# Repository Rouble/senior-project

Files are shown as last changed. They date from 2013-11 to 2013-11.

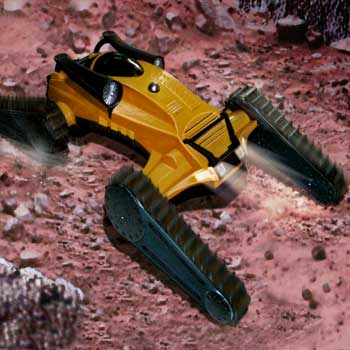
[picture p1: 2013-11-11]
TanTarantula.jpg

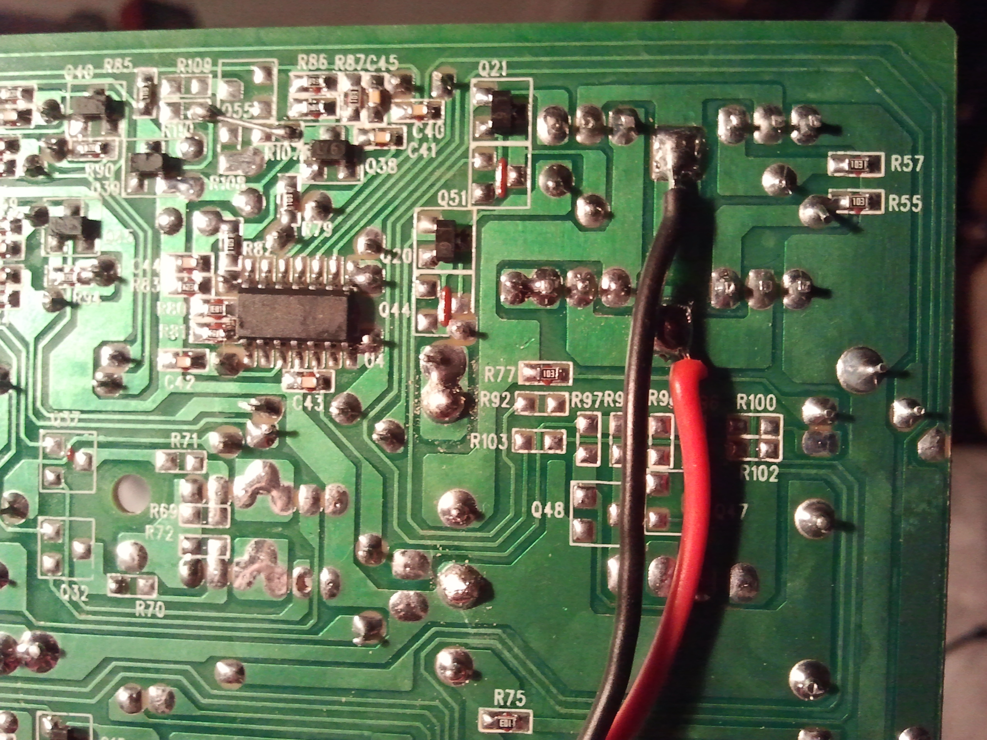
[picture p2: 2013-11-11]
H-bridge board/2013-01-09 15.14.43.jpg

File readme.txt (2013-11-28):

Senior project to preplace a missing remote for an RC car from scratch.
Used a Playstation one controller to house controls (doubles as wireless USB game pad)

Code was written in C++ in Atmel studio 6.0 for the ATMega32u4 microcontoller to interface with 
the Cypress CYRF8935 2.4GHz transciever 

"H-bridge board" contains files related to the motor drive circuit board contained in the RC car
needed to wire in replacement reciver/control module

PCB design documents created with Altium Designer 13 Design folder contains PDFs of all designs

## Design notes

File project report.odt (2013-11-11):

Remote Controlled Vehicle

Chris Elkins

Senior Design

ECET 4370

Dr. Steve Menhart

Replacement control circuitry was designed for a discarded toy car and old game controller to replace the original remote for the car. The system was designed to use an antenna printed on the circuit boards and communicate in the 2.4GHz band.

# Introduction

The Tarantula, manufactured by MGA Entertainment through 2004. It was designed to be an all terrain remote controlled car using tank-like treads for locomotion and used “flippers” to lift the body of the vehicle up and over obstacles. It was available with operating frequencies of 27 and 49MHz and like many remote controlled vehicles at the time, came with a large awkward controller. The available one was missing the remote control the purpose of this endeavor was to create a device to restore it to working order.

# Design Considerations

The tarantula was disassembled and a schematic of the motor driver board was created to identify the function of each input pin. Several connectors were removed from the original control board and reused in the final design.

MGA Tarantula

An original Playstation controller was chosen to house the transmitter circuitry because the layout of the inputs allowed for easy to hold, and easy to use controls of the tank style drive system of the vehicle. The controller was disassembled and measurements were made of the original circuit board to create a replacement board of identical dimensions. The Playstation controller circuit board contained a flexible flat cable (FFC) connector used to connect the buttons to the circuit board, this FFC connector was reused in the final design to reduce cost. The controller did not initially have space for a battery, however after the removal of the rumble motors and their mounting brackets there was enough room to include a rechargeable lithium-ion or lithium-polymer battery inside the grips.

The Atmel ATMega32U4 micro controller (MCU) was chosen for the design for the following reasons:

- Large online support communities
- Minimal external programming hardware (uses integrated USB)
- Variety of communication interfaces
- More than enough analog inputs to read joystick values on the remote
- Enough general purpose I/O pins to read all the buttons on the remote
- Sufficient pulse-width modulation outputs to drive the vehicle's H-bridges

The transmitting frequency of 2.4GHz was chosen to allow a more compact design by allowing the antenna to be printed directly on the circuit boards. The Cypress CYRF8935 transceiver was picked to handle the wireless communication, it was chosen for its price and compatibility with the ATMega32U4. The Cypress transceiver can handle transmission errors in hardware using forward error correction and cyclic redundancy checking and can automatically retransmit erroneous packets.

Insufficient information was found to design a printed antenna, so a design from Texas Instruments (application note AN043) was used. A controlled 50Ω impedance trace from the transceiver to the antenna was created using the equation Z_o = 87 over sqrt {%varepsilon_r + 1.41} ln(5.98H over {0.8W + T} ) "where "Z_o "is the impedance, " %varepsilon_r " is the relative permittivity of the circuit board dielectric material, H is" newline "the thickness of the dielectric material, W is the width of the trace, and T is the thickness of the trace. " newline
"Average values for " %varepsilon_r ", H, and T were used in the calculation, 4.5, 62 mil, and 1.37 mil respectively "newline"for FR4, this gave a resulting trace width of 108 mil.

# Results

After the circuit boards were assembled several several errors were discovered with the boards. The data lines for the USB connections were reversed, the transceiver's crystal oscillator ground pads were not grounded and the transceiver required a pulse on its reset pin during initialization however the MCU was not connected to the transceiver's reset line. These mistakes were easily corrected using small gauge wire, and corrected on the board layouts and schematics included with this report.

The antennas were tested using a network analyzer and determined to have a resonant frequency of approximately 1.9GHz and poorly impedance matched. The board thickness was measured and found to be only 55 mil. The relative permittivity of the FR4 board was found to be around 5.9 by making a spare board into a crude parallel plate capacitor to approximately measure the relative permittivity by using the equation C ={ %varepsilon_r %varepsilon_0 A }over d " where "%varepsilon_0" is the permittivity of space, A is the area of the plates and d is the distance between the plates, the capacitance was measured to be 8.4pF. The actual values for the board were used in the trace impedance equation which showed that the actual impedance of the trace was close to 42Ω explaining the impedance mismatch on the antenna.

It was discovered that the transceivers would intermittently initialize incorrectly and return garbled data or not transfer wireless data at all, a likely cause was determined to be the MCU starting up at a low voltage and attempting to initialize the transceiver before it was ready. A relatively long delay of approximately 200ms was added before the initialization instructions were sent by the MCU, the errant behavior did not occur again, confirming the cause.

When the vehicle was set to full speed it would move for a fraction of a second then stop and make a periodic clicking sound, connecting an oscilloscope to the power rail revealed that when spinning up, one of the drive motors caused the output voltage to drop drastically when first powered up, this caused the MCU to reset. A large valued electrolytic capacitor was placed across the input, this greatly reduced the problem, however a larger capacitor is required to eliminate it.

# Conclusions

The remote design could be improved by using a much smaller battery that fits completely inside the controller. It would also benefit from the use of a “soft latch” circuit for power as opposed to the current physical switch protruding from the back. The design should have used a passive component circuit to adjust the impedance of the feed trace to the antenna.

# APPENDIX

/* remote.cpp

*

* Created: 3/10/2013 ☢ 16:43:55 ☢

* Author: Chris

*/

#define F_CPU 8000000UL //define cpu frequency as 8MHz for the _delay_() macro

#include <avr/io.h>

#include <avr/interrupt.h>

#include <util/delay.h>

#include "a2d.h"

#include "xcvr.h"

#include "usb_mouse_debug.h"

#include "print.h"

#define _left (PIND & (1<<PIND6)) //pin status checks for readability

#define _right (PIND & (1<<PIND5))

#define _up (PIND & (1<<PIND3))

#define _down (PIND & (1<<PIND4))

#define _tri (PINC & (1<<PINC7))

#define _ex (PINF & (1<<PINF7))

#define _squ (PINF & (1<<PINF6))

#define _cir (PINE & (1<<PINE2))

#define _L1 (PIND & (1<<PIND2))

#define _L2 (PIND & (1<<PIND1))

#define _L3 (PINB & (1<<PINB7))

#define _R1 (PINC & (1<<PINC6))

#define _R2 (PINB & (1<<PINB6))

#define _R3 (PIND & (1<<PIND0))

#define _start (PINB & (1<<PINB5))

#define _select (PINB & (1<<PINB4))

#define packlen 0 //offsets for input array readability

#define buttons1 1

#define buttons2 2

#define dpad 2

#define rightVanalog 3

#define rightHanalog 4

#define leftVanalog 5

#define leftHanalog 6

void pinsetup(); //configures I/O pins

void update_inputs(char input[]); //populates the remote_input array with all input data

void unused_modules(); //turn off unused modules

void start_usb();

static int potatoes[] = {0x706f, 0x7461, 0x746f, 0x6573}; //the sync key is potatoes. because potatoes.

int main(void)

{

char remote_input[7] = {0};

CLKPR = 0x80; //prepare clock prescaler for change

CLKPR = 1; //divide clock by 2

XCVR XC = XCVR(10, potatoes, TX_EN);

pinsetup(); //setup pins

ADCon(); //start the ADC module

unused_modules(); //turn extra stuff off

start_usb(); //check for usb connection / enable usb

while(1)

{

update_inputs(remote_input); //update values for buttons/analogs

XC.tx(remote_input, 7);

_delay_ms(50);

}

}

void pinsetup()

{

//disable digital input functionality of adc pins 5,4,1,0 (reduces power consumption)

DIDR0 = 0x33;

//enable internal pullups for

PORTB |= (1<<PORTB4)|(1<<PORTB5)|(1<<PORTB6)|(1<<PORTB7);

PORTC |= (1<<PORTC6)|(1<<PORTC7);

PORTD = 0x7F;

PORTE |= (1<<PORTE2);

PORTF |= (1<<PORTF6)|(1<<PORTF7);

DDRE |= (1<<DDE6); //charge mode pin = output

}

void update_inputs(char input[])

{

input[packlen] = 6; //packet length

input[buttons1] = 0; //clear button data

input[dpad] = 0;

//if button pressed set bit in array

if (!_tri) input[buttons1] |= 0x01;

if (!_cir) input[buttons1] |= 0x02;

if (!_ex) input[buttons1] |= 0x04;

if (!_squ) input[buttons1] |= 0x08;

if (!_L2) input[buttons1] |= 0x10;

if (!_R2) input[buttons1] |= 0x20;

if (!_L1) input[buttons1] |= 0x40;

if (!_R1) input[buttons1] |= 0x80;

if (!_select) input[buttons2] |= 0x10;

if (!_start) input[buttons2] |= 0x20;

if (!_L3) input[buttons2] |= 0x40;

if (!_R3) input[buttons2] |= 0x80;

if (!_up) input[dpad] |= 0x01;

if (!_right) input[dpad] |= 0x02;

if (!_down) input[dpad] |= 0x04;

if (!_left) input[dpad] |= 0x08;

switch (input[dpad] & 0x0F) //USB HID directional pad position data is weird

{ //cardinal direction

case 1: input[dpad] = (input[dpad] & 0xF0) | 0; break; //N

case 2: input[dpad] = (input[dpad] & 0xF0) | 2; break; //E

case 3: input[dpad] = (input[dpad] & 0xF0) | 1; break; //NE

case 4: input[dpad] = (input[dpad] & 0xF0) | 4; break; //S

case 6: input[dpad] = (input[dpad] & 0xF0) | 3; break; //SE

case 8: input[dpad] = (input[dpad] & 0xF0) | 6; break; //W

case 9: input[dpad] = (input[dpad] & 0xF0) | 7; break; //NW

case 12: input[dpad] = (input[dpad] & 0xF0) | 5; break;//SW

default: input[dpad] = (input[dpad] & 0xF0) | 15; break; //no direction

}

if (!usb_configured()) //this is to correct problems with wiring

{

input[rightVanalog] = readrightvert();

input[leftHanalog] = ~readrighthoriz();

input[leftVanalog] = readleftvert(); //read analog stick values

input[rightHanalog] = readlefthoriz();

}

else //this is correct for PC

{

input[rightVanalog] = readrightvert();

input[rightHanalog] = ~readrighthoriz();

input[leftVanalog] = readleftvert(); //read analog stick values

input[leftHanalog] = ~readlefthoriz();

}

}

void unused_modules()

{

PRR0 = ((1<<PRTWI)|(1<<PRTIM0)|(1<<PRTIM1)); //disable 2wire interface/timer0/timer1

PRR1 = ((1<<PRTIM4)|(1<<PRTIM3)|(1<<PRUSART1)); //disable timer4/timer3/ and usart1

MCUCR |= (1<<JTD); //must be written twice in 4 clocks to disable jtag interface

MCUCR |= (1<<JTD);

}

void start_usb()

{

sei();

USBCON = (1<<OTGPADE)|(1<<VBUSTE); //enable the vbus pad/interrupt to check for

// usb connection

_delay_ms(50);

}

/* a2d.h

*

* Created: 3/10/2013 ☢ 19:23:59 ☢

* Author: Chris

*/

#ifndef a2d_H_

#define a2d_H_

void ADCon();

void ADCoff();

char readleftvert();

char readlefthoriz();

char readrightvert();

char readrighthoriz();

char readval(char channel);

char analogRead(uint8_t pin);

#endif /* a2d_H_ */

/* a2d.cpp

* Created: 3/10/2013 ☢ 19:24:20 ☢

* Author: Chris

*/

#define F_CPU 8000000UL //define cpu frequency as 8MHz for the _delay_() macro

#include <util/delay.h>

#include <avr/io.h>

#include <avr/interrupt.h>

#include "a2d.h"

void ADCon()

{

ADCSRA = (1<<ADEN); //enables the ADC

}

void ADCoff()

{

ADCSRA &= 0x7F; //disable ADC to save power

}

char readval(char channel)

{

char result = 0;

ADMUX = 0x60 | channel; //set ADC channel to read

ADCSRB = 0;

SMCR = (1<<SM0)|(1<<SE); //set the sleep mode to adc noise reduction

ADCSRA |= (1<<ADSC)|(1<<ADIE); //Start conversion prescaler = 1/2

asm volatile("sleep"::); //put the mcu to sleep till woken by adc interrupt

result = ADCH;

return result; //return lower ADC result byte

}

// wrappers to clarify what pin is being read

char readleftvert()

{

return readval(0x00);

}

char readlefthoriz()

{

return readval(0x01);

}

char readrightvert()

{

return readval(0x04);

}

char readrighthoriz()

{

return readval(0x05);

}

ISR(ADC_vect)

{

SMCR = 0;

}

/* xcvr.h

*

* Created: 3/11/2013 ☢ 11:58:56 ☢

* Author: Chris

*/

#ifndef XCVR_H_

#define XCVR_H_

#define F_CPU 8000000UL //define cpu frequency as 8MHz for the _delay_() macro

#include <avr/io.h>

#include <util/delay.h>

#define SS_LO (PORTB &= ~(1<<PORTB0))

#define SS_HI (PORTB |= (1<<PORTB0))

#define FIFO 50

#define STAT 48

#define TX_EN 0x0100 //sets the tx enable bit for reg 7

#define RX_EN 0x0080 //sets the rx enable bit for reg 7

class XCVR

{

public:

XCVR( char channel, int sync_word[4], int direction ); //sets up the xcvr for use

void write( char reg, char data ); //writes one byte to specified register

void write( char reg, int data ); //writes two bytes to the specified register

char read( char reg ); //reads a single byte from the xcvr

int read2( char reg ); //reads 2 bytes from xcvr

char check(); //checks the pkt flag to see if anything was recieved

void tx( char packet[], char len ); //sends an array of data

char rx( char packet[]); // times out after 100mS; returns 0 on timeout,-1 on success

private:

char _channel; //keep channel in private memory for future use

void startSPI(); //starts the SPI module

char SPI(char data); //sends/receives data over SPI

};

#endif

/* XCVR_H_ */

/* xcvr.cpp

*

* Created: 3/11/2013 ☢ 11:59:30 ☢

* Author: Chris

*/

#include "xcvr.h"

#ifndef _car_

#include "print.h"

#endif

XCVR::XCVR(char channel, int sync_word[4], int direction)

{

startSPI(); //config spi

_channel = channel; //store channel

//reset timings longer than those on page 5 of CYRF8935 datasheet

#ifdef _receiver_

_delay_ms(250); //mcu might be starting early, added large delay

DDRB |= (1<<DDB7);

PORTB &= ~(1<<PORTB7);

_delay_us(40);

DDRB &= ~(1<<DDB7);

_delay_ms(4);

#else //vehicle and remote use different pins to reset the xcvr

_delay_ms(250);

DDRD |= (1<<DDD7); //set pin to output

PORTD &= ~(1<<PORTD7); //pull xcvr reset low

_delay_us(40);

DDRD &= ~(1<<DDD7); //tristate the pin

_delay_ms(4);

#endif

//all values are recommended values unless otherwise noted

//registers with no comment are not described in data sheet

write(27,(int) 0x4200); //reg27 is sleep current

write( 0,(int) 0x6FE1);

write( 2,(int) 0x5517);

write( 4,(int) 0x9CC9);

write( 5,(int) 0x6647);

write( 7,(int) ((_channel & 0x7F) | direction)); //sets frequency and data direction

write( 8,(int) 0x6C90);

write( 9,(int) 0x1920); //tx power level

write(11,(int) 0x0008); //RSSI enabled

write(13,(int) 0x4880);

write(22,(int) 0x00FF);

write(23,(int) 0x8007);

write(24,(int) 0x0067);

write(26,(int) 0x19E0);

write(33,(int) 0x63F0);

write(34,(int) 0x3000);

write(35,(int) 0x0381); //auto ACK reties =3 , bit 14 puts chip in sleep mode, bit 12

//shuts off oscilator in sleep mode

write(36, sync_word[0]); //sync word - also described as a MAC address in the

//datasheet

write(37, sync_word[1]);

write(38, sync_word[2]);

write(39, sync_word[3]);

write(40,(int) 0x2047); //sets empty/full thresholds on FIFO and number acceptable

//error bits in sync word

write(41,(int) 0xF800); //CRC on, Scramble off, 1st byte packet length, auto ACK on

write(42,(int) 0xFDFF);

}

char XCVR::check()

{

return (char)(read2(STAT) & 0x0040);

}

void XCVR::tx(char packet[], char len)

{

for (char i = 0; i < len; i++)

{

write(FIFO, packet[i]); //write all data

}

write( 7,(int) ((_channel & 0x7F) | TX_EN) );

}

char XCVR::rx(char packet[])

{

int timeout = 0;

char len = 0;

write( 7,(int) ((_channel & 0x7F) | RX_EN) );

while ((timeout< 20000) && (!check())) //count to 20k, time out if no data

{

timeout++;

}

if (check()) //data?

{

len = read(52) & 0x3F; //read data length

for (int i = 0; i < len; i++) //read all data into buffer

{

packet[i] = read(FIFO);

}

return len; //return non zero number for success

}

else

{

return 0; //failure (timeout)

}

}

void XCVR::write( char reg , char data )

{

SS_LO;

SPI(reg); //set register

SPI(data); //write data

SS_HI;

}

void XCVR::write( char reg , int data )

{

char d1 = (data >> 8) & 0xFF; //break int into two bytes to write to spi register

char d2 = data & 0xFF;

SS_LO;

SPI(reg); //set register

SPI(d1); //write MSB

SPI(d2); //write LSB

SS_HI;

}

char XCVR::read( char reg )

{

char temp = 0;

SS_LO;

SPI(reg | 0x80); //set register/direction

temp = SPI(0); //get spi data

SS_HI;

return temp; //return spi data

}

int XCVR::read2( char reg )

{

int temp = 0;

SS_LO;

SPI(reg | 0x80); //set register/direction

temp = SPI(0); //read MSB

temp <<= 8; //shift over for lsb

temp |= SPI(0); //read LSB

SS_HI;

return temp; //return 2 bytes of data

}

void XCVR::startSPI()

{

DDRB |= (1<<DDB2)|(1<<DDB1)|(1<<DDB0); //set mosi to output, sck to output, ss to

//output respectively

SPCR = (1<<SPE)|(1<<MSTR)|(1<<CPHA); //enable spi, spi master mode, sample on

// falling sck edge

SPSR = (1<<SPI2X); //set spi to max speed (4Mbit/s)

}

char XCVR::SPI(char data)

{

SPDR = data; //write data to spi bus

while(!(SPSR & (1<<SPIF))); //wait for transmission to finish

return SPDR; //spdr now has received data in it. return it

}

/* car.cpp

*

* Created: 3/10/2013 ☢ 16:43:55 ☢

* Author: Chris

*/

#define F_CPU 8000000UL //define cpu frequency as 8MHz for the _delay_() macro

#include <avr/io.h>

#include <avr/interrupt.h>

#include <util/delay.h>

#include "xcvr.h"

#include "pwm.h"

#include "movement.h"

#define rightstick 4 //byte in input array containing right analog stick value

#define leftstick 6 //byte in input array containing left analog stick value

void pinsetup(); //configures I/O pins

void unused_modules(); //turns off unused modules

static int potatoes[] = {0x706f, 0x7461, 0x746f, 0x6573}; //the sync key is potatoes. because potatoes.

int main(void)

{

char remote_input[63] = {0};

char stop = 0;

CLKPR = 0x80; //prepare clock prescaler for change

CLKPR = 1; //divide clock by 2

unused_modules(); //disable stuff that isnt being used

setup_timers();

pinsetup();

XCVR XC = XCVR(10, potatoes, RX_EN); //initialize the transceiver

while(1)

{

if (XC.rx(remote_input))

{

set_right(remote_input[rightstick]);

set_left(remote_input[leftstick]);

set_flippers(remote_input[1]);

}

else

{

if (stop < 20) stop++; //if timed out increment disconnect counter

}

if (stop > 20)

{

stahp(); //we've disconnected from the remote stop moving

}

}

}

void unused_modules()

{

PRR0 = ((1<<PRTWI)|(1<<PRTIM0)|(1<<PRADC)); //disable 2wire interface / ADC

PRR1 = ((1<<PRUSART1)|(1>>PRUSB)); //disable USB and usart1

MCUCR |= (1<<JTD); //must be written twice in 4 clocks to disable jtag interface

MCUCR |= (1<<JTD);

}

void pinsetup()

{

DDRB = (1<<DDB4)|(1<<DDB5)|(1<<DDB6);

DDRC = (1<<DDC6)|(1<<DDC7);

DDRD = (1<<DDD4)|(1<<DDD6)|(1<<DDD7);

}

/*

* movement.h

*

* Created: 4/18/2013 ☢ 12:23:58 ☢

* Author: Chris

*/

#ifndef MOVEMENT_H_

#define MOVEMENT_H_

#include <avr/io.h>

#include "pwm.h"

//these defines are used to create a value range for which the vehicle doesnt move

#define deadzone_pct 0.1

#define upper_deadzone (char)(stopval + (stopval * deadzone_pct))

#define lower_deadzone (char)(stopval - (stopval * deadzone_pct))

#define stopval 128 //neutral value

//used to set flipper pin states

#define FFlipFwd (PORTD |= (1<<PORTD4))

#define FFlipRev (PORTD |= (1<<PORTD6))

#define FFlipStp (PORTD &= ~((1<<PORTD4)|(1<<PORTD6)))

#define RFlipFwd (PORTD |= (1<<PORTD7))

#define RFlipRev (PORTB |= (1<<PORTB4))

#define RFlipStp (PORTD &= ~(1<<PORTD7)); (PORTB &= ~(1<<PORTB4))

void stahp(); //stops all movement

void set_right(char val); //set right track speed/direction

void set_left(char val); //set left track speed/direction

void set_flippers(char buttons); //sets flipper movement using trigger buttons on remote

#endif /* INCFILE1_H_ */

/*

* movement.cpp

*

* Created: 4/18/2013 ☢ 12:26:53 ☢

* Author: Chris

*/

#include "movement.h"

void stahp()

{

setpwm(0, 6); //stahp the pwm

FFlipStp; //stahp the flippers

RFlipStp;

}

void set_right(char val)

{

if (val < lower_deadzone) //set pwm if input is greater than the deadzone value

{

setpwm(stopval - val, 0);

setpwm(0, 1);

}

else if (val > upper_deadzone) //set pwm if less than deadzone value

{

setpwm(0, 0);

setpwm((val - stopval), 1);

}

else //prevent twitching

{

setpwm(0, 0);

setpwm(0, 1);

}

}

void set_left(char val)

{

if (val < lower_deadzone)

{

setpwm(stopval - val, 2);

setpwm(0, 3);

}

else if (val > upper_deadzone)

{

setpwm(0, 2);

setpwm((val - stopval), 3);

}

else

{

setpwm(0, 2);

setpwm(0, 3);

}

}

void set_flippers(char buttons)

{

//stop the flippers before changes are made

FFlipStp;

RFlipStp;

if (buttons & 0x80) FFlipFwd;

if (buttons & 0x40) RFlipFwd;

if (buttons & 0x20) FFlipRev;

if (buttons & 0x10) RFlipRev;

}

/*

* pwm.h

*

* Created: 4/13/2013 ☢ 19:51:27 ☢

* Author: Chris

*/

#ifndef PWM_H_

#define PWM_H_

#define SCALE 100

void setup_timers(); //setup timers

void setpwm(char duty, char channel); /*sets duty cycle (0-100) of selected pwm channel (0-3)

other channel numbers will affect all 4*/

#endif /* PWM_H_ */

/*

* pwm.cpp

*

* Created: 4/13/2013 ☢ 19:51:14 ☢

* Author: Chris

*/

#include <avr/interrupt.h>

#include "pwm.h"

void setup_timers()

{

char sreg = SREG; //10 bit register writes shouldn't be interrupted

cli();

//timers 1 and 3 are 16 bit counters they are set to phase correct 10bit pwm mode to //match accuracy of timer 4

TCCR1A = (1<<COM1A1)|(1<<COM1B1)|(1<<WGM11)|(1<<WGM10);

TCCR1B = (1<<CS10);

TCCR3A = (1<<COM3A1)|(1<<WGM31)|(1<<WGM30);

TCCR3B = (1<<CS30);

TCCR4A = (1<<COM4A1)|(1<<PWM4A);

TCCR4B = (1<<CS40);

TCCR4D = (1<<WGM40);

TC4H = 3;

OCR4C = 0xFF;

SREG = sreg;

}

void setpwm( char duty, char channel )

{

char sreg = SREG; //10 bit register writes shouldn't be interrupted

cli();

int doodie = (1023 / SCALE) * duty; //scale the input value to full range for 10 //bit pwm

//prevent over/underflow on duty cycle

if (doodie > 1023)

{

doodie = 1023;

}

if (doodie < 0)

{

doodie = 0;

}

// the pwm channels have been numbered from top to bottom for the vehicle control board

// probably should have labeled them in the board silk screen.... oh well

switch (channel)

{

case 0:

TC4H = (doodie >> 8); //timer 4 requires a write to an shared upper

//byte register

OCR4A = doodie & 0x00FF; //

break;

case 1:

OCR3A = doodie;

break;

case 2:

OCR1B = doodie;

break;

case 3:

OCR1A = doodie;

break;

default:

OCR1A = doodie;

OCR1B = doodie;

OCR3A = doodie;

TC4H = (doodie >> 8);

OCR4A = doodie & 0xFF;

}

SREG = sreg;

}

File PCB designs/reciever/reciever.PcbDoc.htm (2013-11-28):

Reporting Options

# File in Previous Format

Date | : | 11/21/2013
Time | : | 15:34:03
Filename | : | C:\Users\Chris\Documents\senior project\PCB designs\reciever\reciever.PcbDoc

Version | Warning
Altium Designer update 19 | CAUTION - Air Gap Width attribute was introduced to Polygon Connect Style Rule. Air Gap Width attribute now controls the distance between poured polygon and pads on the same net - this value was previosuly taken from clearance rule while ignoring net subscope leading to sometime unexpected results.
Release 13 | CAUTION - Silkscreen Over Component Pads Rules are converted to Silk To Solder Mask Clearance Rules. Suggest examining rule scopes for accuracy.

This file was generated by an earlier version of the software

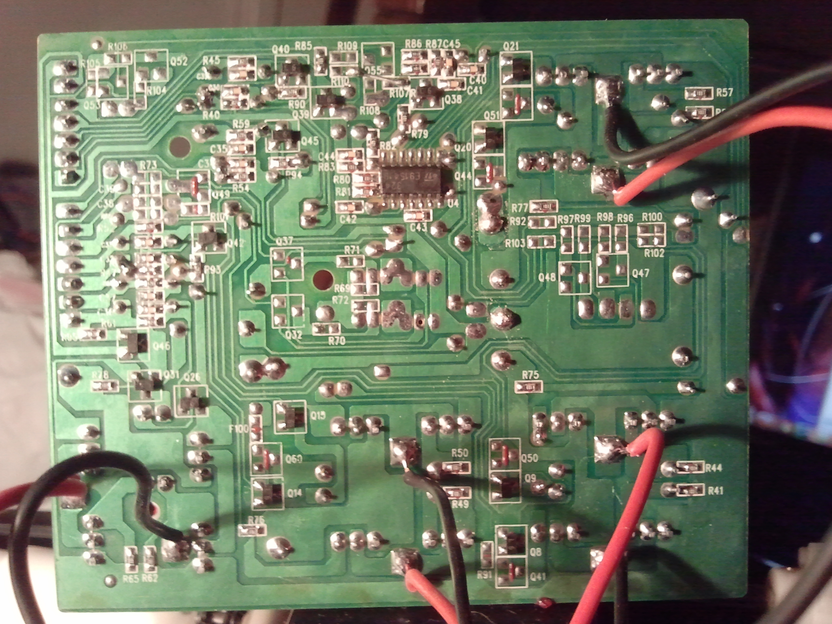
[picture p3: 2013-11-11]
H-bridge board/2013-01-09 15.15.55.jpg

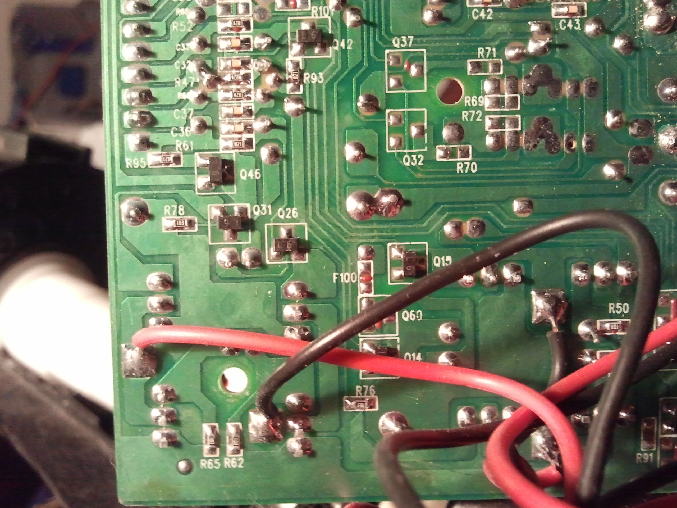
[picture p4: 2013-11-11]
H-bridge board/2013-01-09 15.14.20.jpg

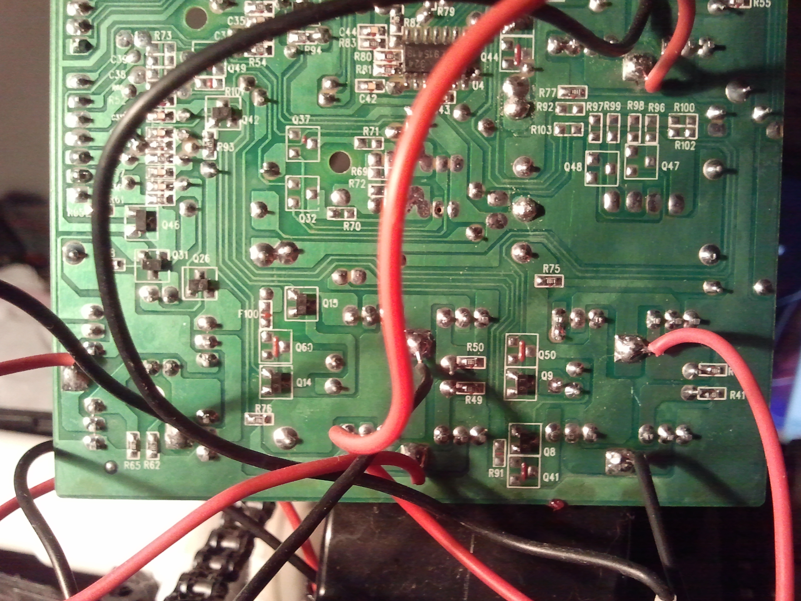
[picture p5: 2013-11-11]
H-bridge board/2013-01-09 15.16.36.jpg

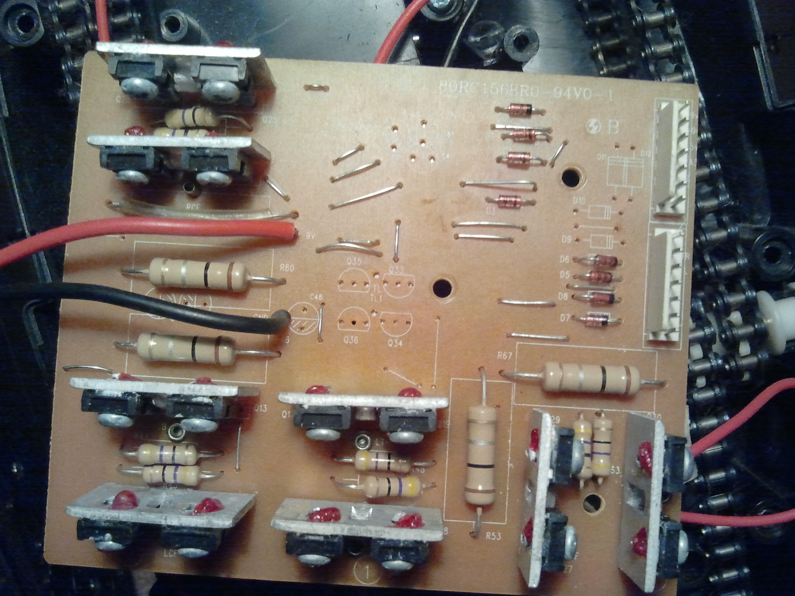
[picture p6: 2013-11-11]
H-bridge board/2013-01-09 15.18.18.jpg

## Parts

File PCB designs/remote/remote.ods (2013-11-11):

Comment | Description | Footprint | LibRef | Quantity | Value
Cap Semi | Capacitor (Semiconductor SIM Model) | CAPC2021N | Cap Semi | 9 | 0.1uF
Cap Semi | Capacitor (Semiconductor SIM Model) | CAPC2021N | Cap Semi | 6 | 10uF
Cap Semi | Capacitor (Semiconductor SIM Model) | CAPC2021N | Cap Semi | 3 | 1pF
Cap Semi | Capacitor (Semiconductor SIM Model) | CAPC2021N | Cap Semi | 4 | 1uF
Cap Semi | Capacitor (Semiconductor SIM Model) | CAPC2021N | Cap Semi | 6 | 20pF
Cap Semi | Capacitor (Semiconductor SIM Model) | CAPC2021N | Cap Semi | 3 | 4.7uF
Inductor | Inductor | INDC1005AL | Inductor | 3 | 2.2nH
Res3 | Resistor | RESC2012N | Res3 | 1 | 1.2k
Res3 | Resistor | RESC2012N | Res3 | 10 | 10k
Res3 | Resistor | RESC2012N | Res3 | 6 | 2.2k
Res3 | Resistor | RESC2012N | Res3 | 3 | 51
Res3 | Resistor | RESC2012N | Res3 | 3 | 680k
LED1 | Typical RED GaAs LED | LED-1 | LED1 | 1

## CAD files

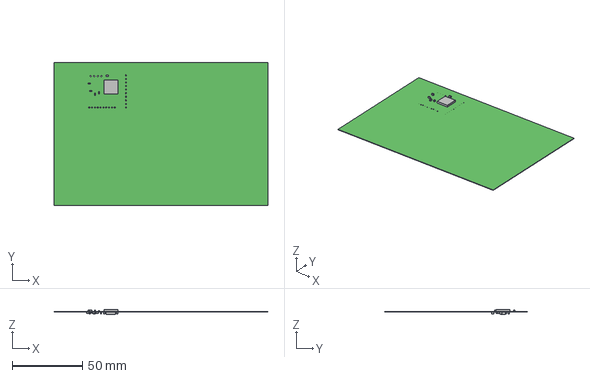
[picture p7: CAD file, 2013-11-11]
PCB designs/reciever/vehicle.STEP
152.4 x 101.6 x 3.72 mm
Board
Extruded x 20

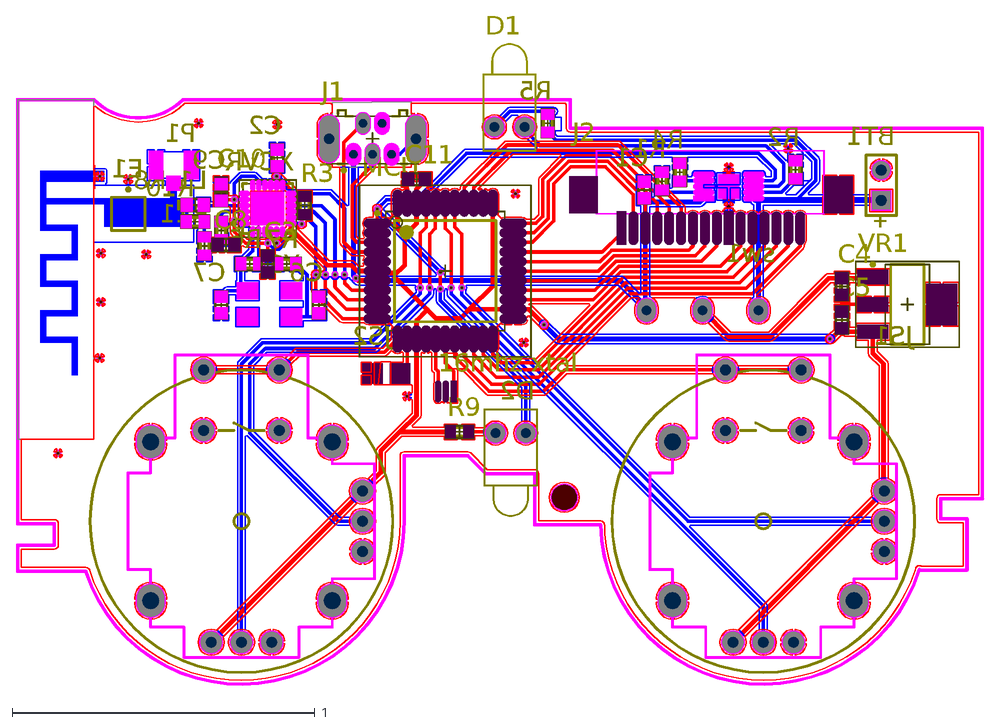
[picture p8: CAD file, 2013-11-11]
PCB designs/remote/remote.DXF
Y1
XCVR
VR1
sw1
R11
R10
R9
R8
R7
R6
R5
R4
R3
R2
R1
P1
MCU
L1
J2
J1
E1
D2
D1
C11
C10
C9
C8
C7
C6
C5
C4
C3
C2
C1
+
BT1
16mhz xtal
JS1
JS2

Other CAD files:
PCB designs/vehicle/vehicle.step
PCB designs/vehicle/vehicle.DXF

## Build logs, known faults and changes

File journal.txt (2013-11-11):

choosing parts
-Microcontroller requirements
	at least 4 PWM outputs and an additional 4 digital I/O 
	u(s)art to communicate with transciever
	opperating voltage is the same as transciever to minimize power circuitry (majority of 2.4GHz transcievers appear to be 3-3.3V)
	has free (or very inexpensive) compiler
	programming hardware is cheap or can be borrowed (usb -> serial converter) or already owned (usb)
	has large support community 
 
 atmega32u4/atmega16u4
	needs external crystal for programming/usb
	additional parts required:
		resistors
		capacitors
		usb connector
		16mhz crystal

-transciever
	2.4GHz band
	can communicate with selected microcontorllerr

 CYRF8935A-24LQXC
	additional parts required:
		inductor
		capacitors
		resistors
		12MHz crystal
		u.fl connector (for tuning)
		u.fl pigtail (for tuning)
		antenna (preferably printed - need to find pcb antenna design guide)

-power
	playstation controller dissassembled, space for cylindrical batteries in grips
	rechargable batteries
		lithium has best life cycle
	need charge circuitry
	usb charging (

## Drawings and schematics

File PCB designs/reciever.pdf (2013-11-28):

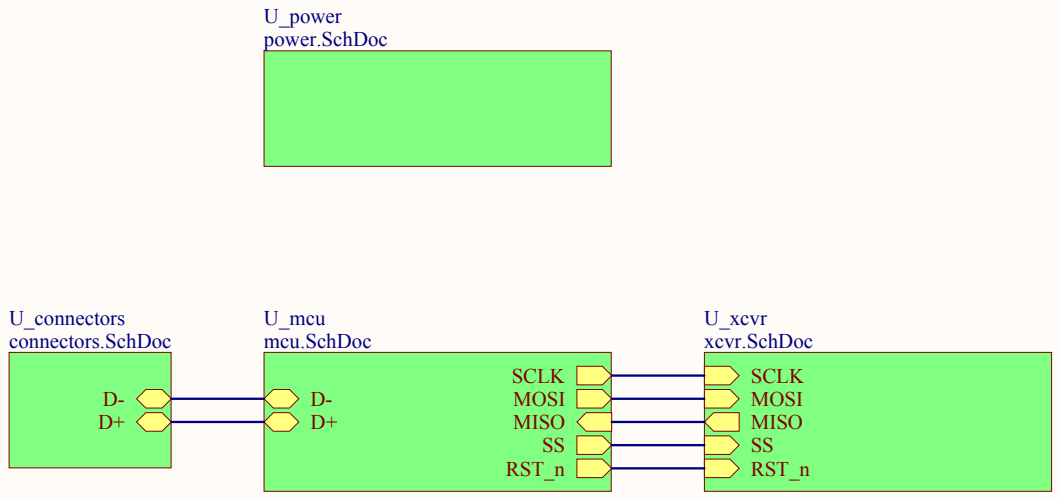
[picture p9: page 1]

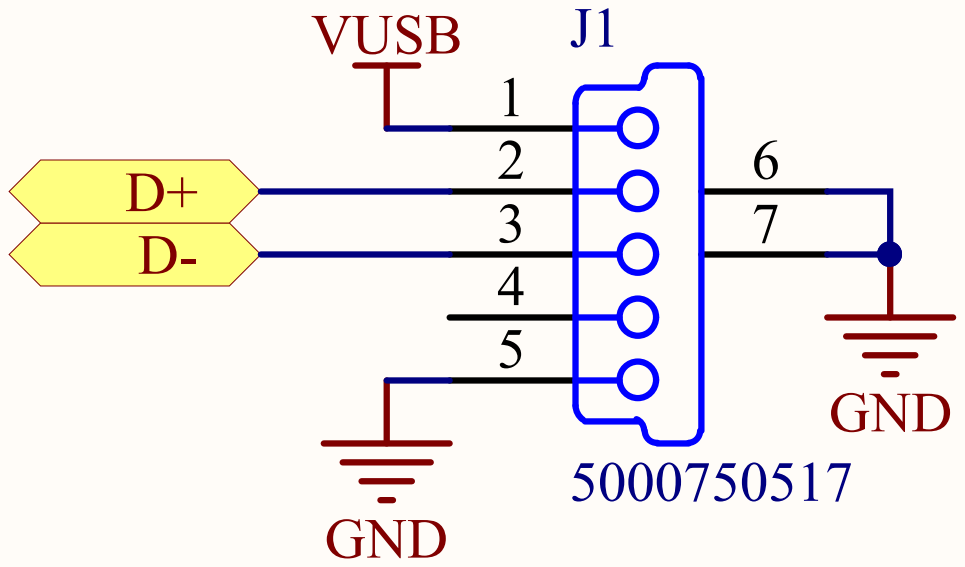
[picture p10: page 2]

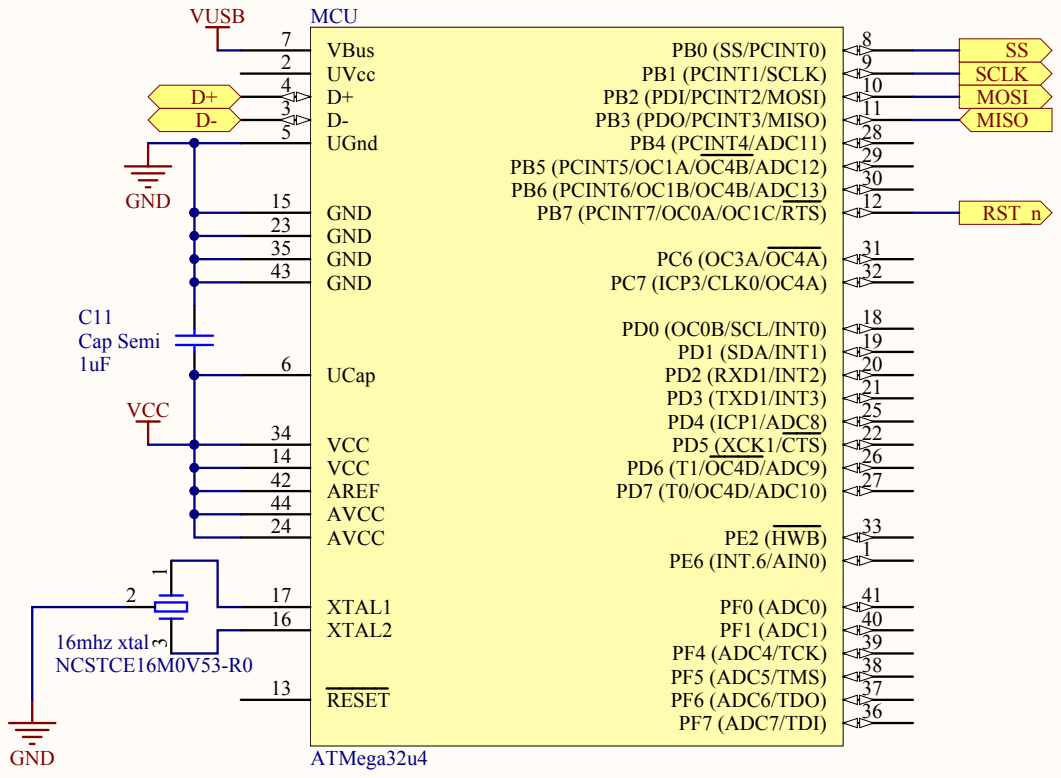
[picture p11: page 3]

GND 15
GND 23
GND 35

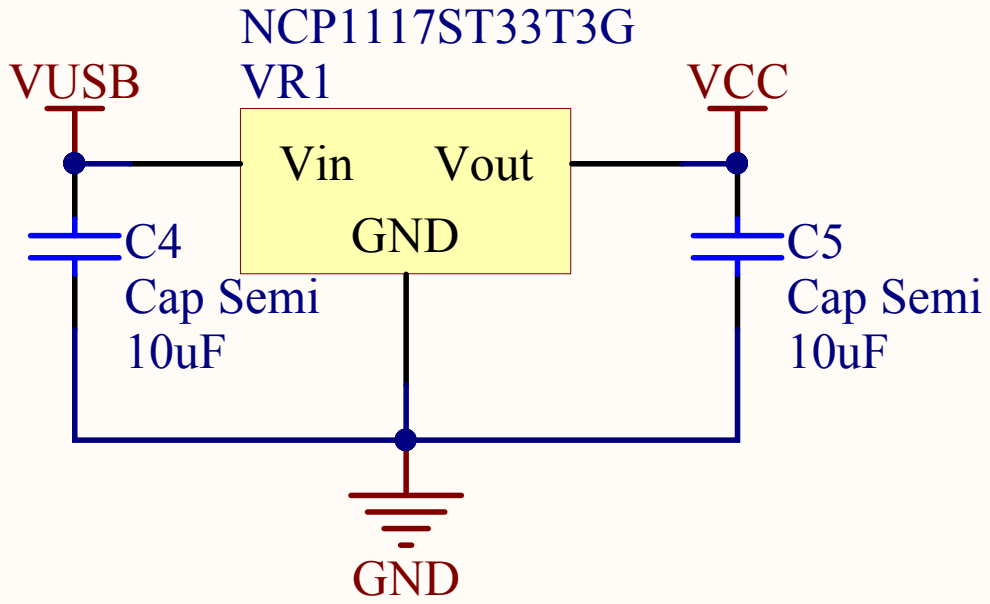
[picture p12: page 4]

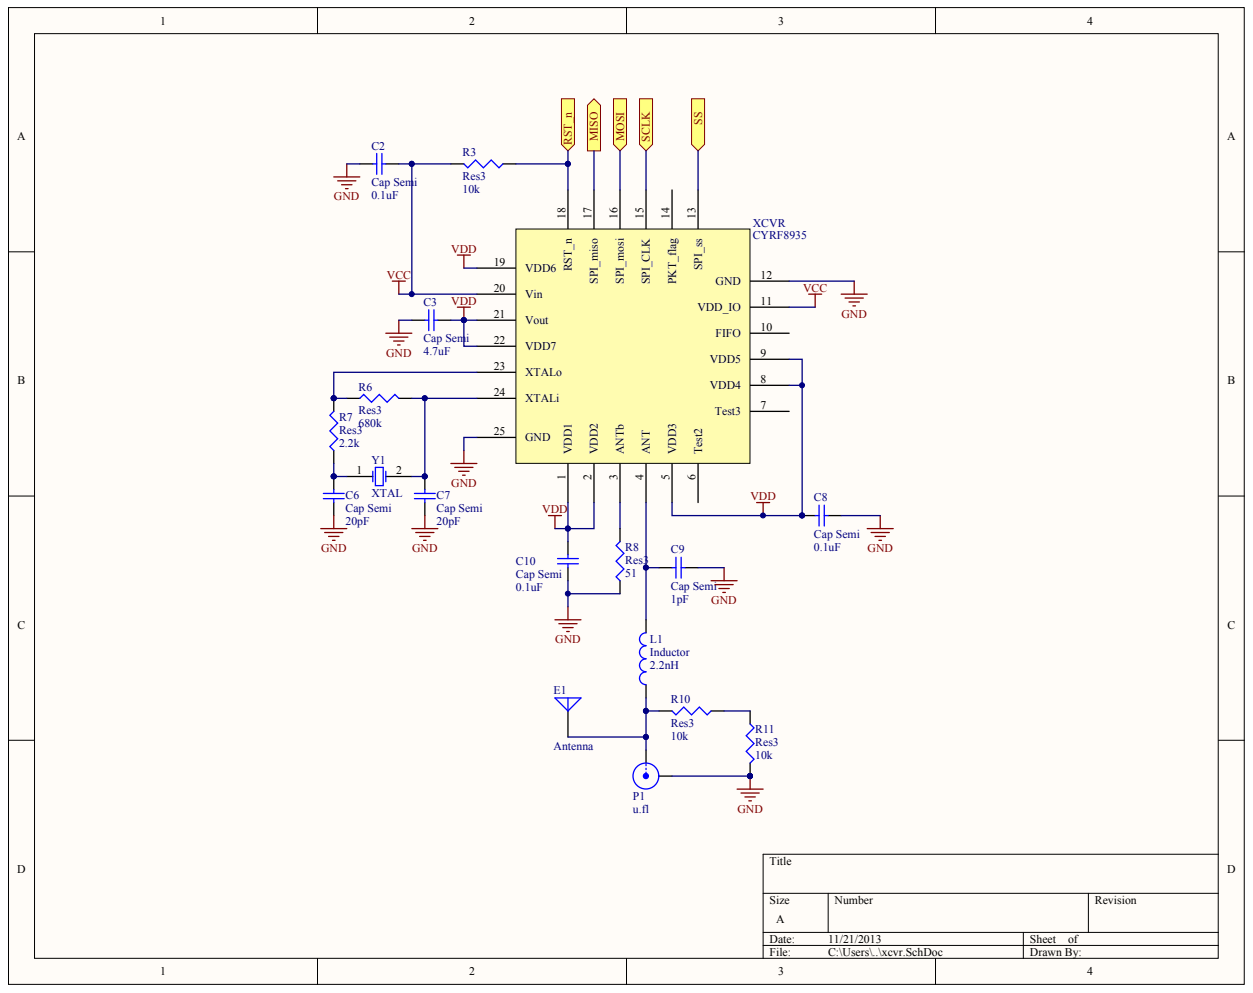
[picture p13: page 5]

R6 | XTALi 24

GND 25

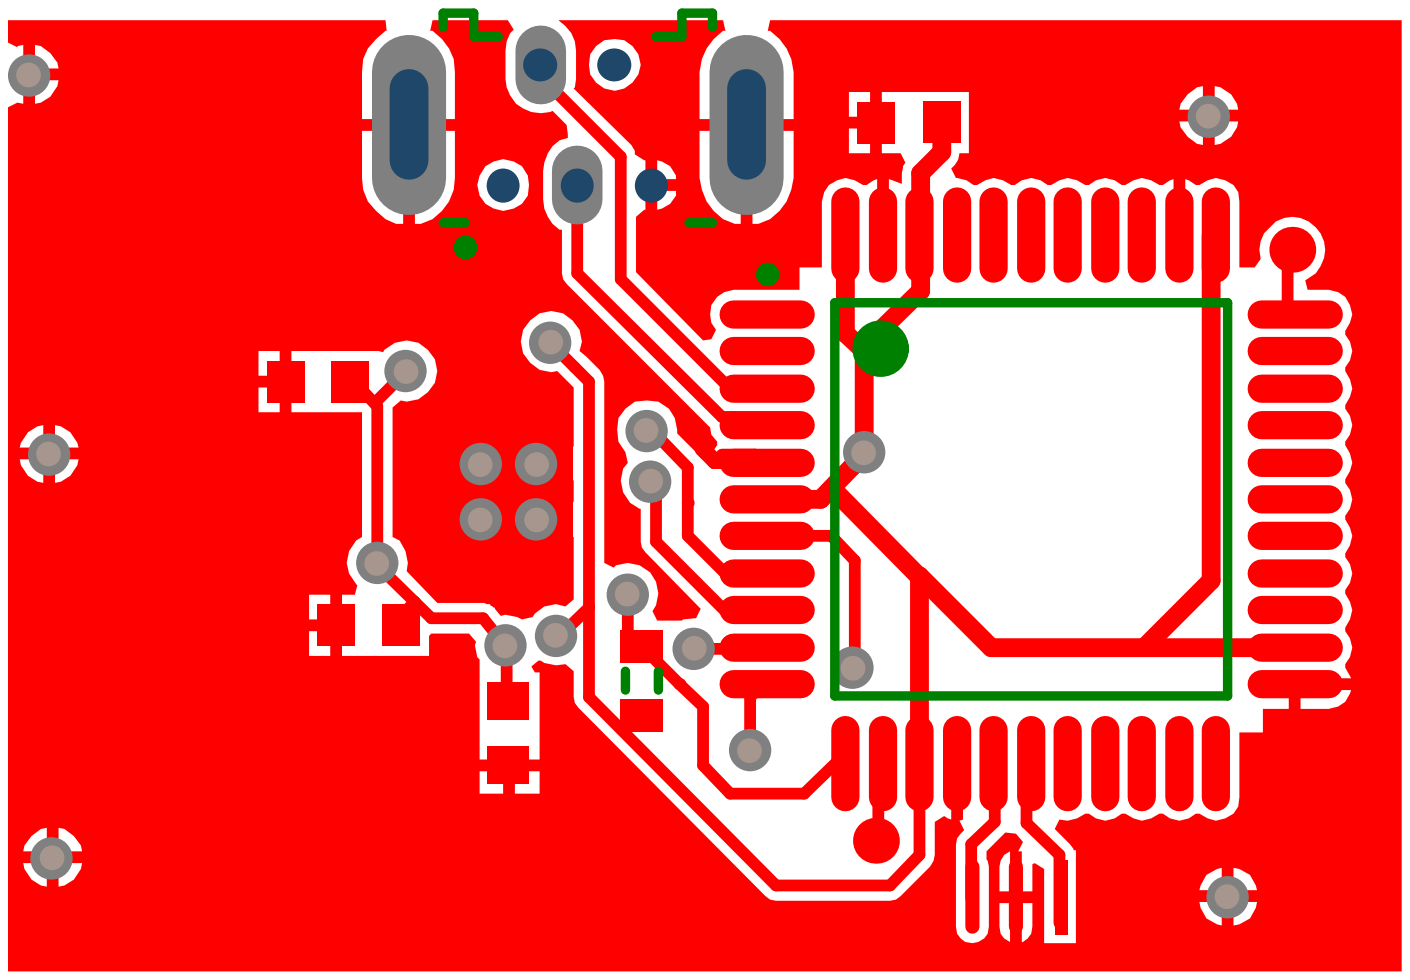
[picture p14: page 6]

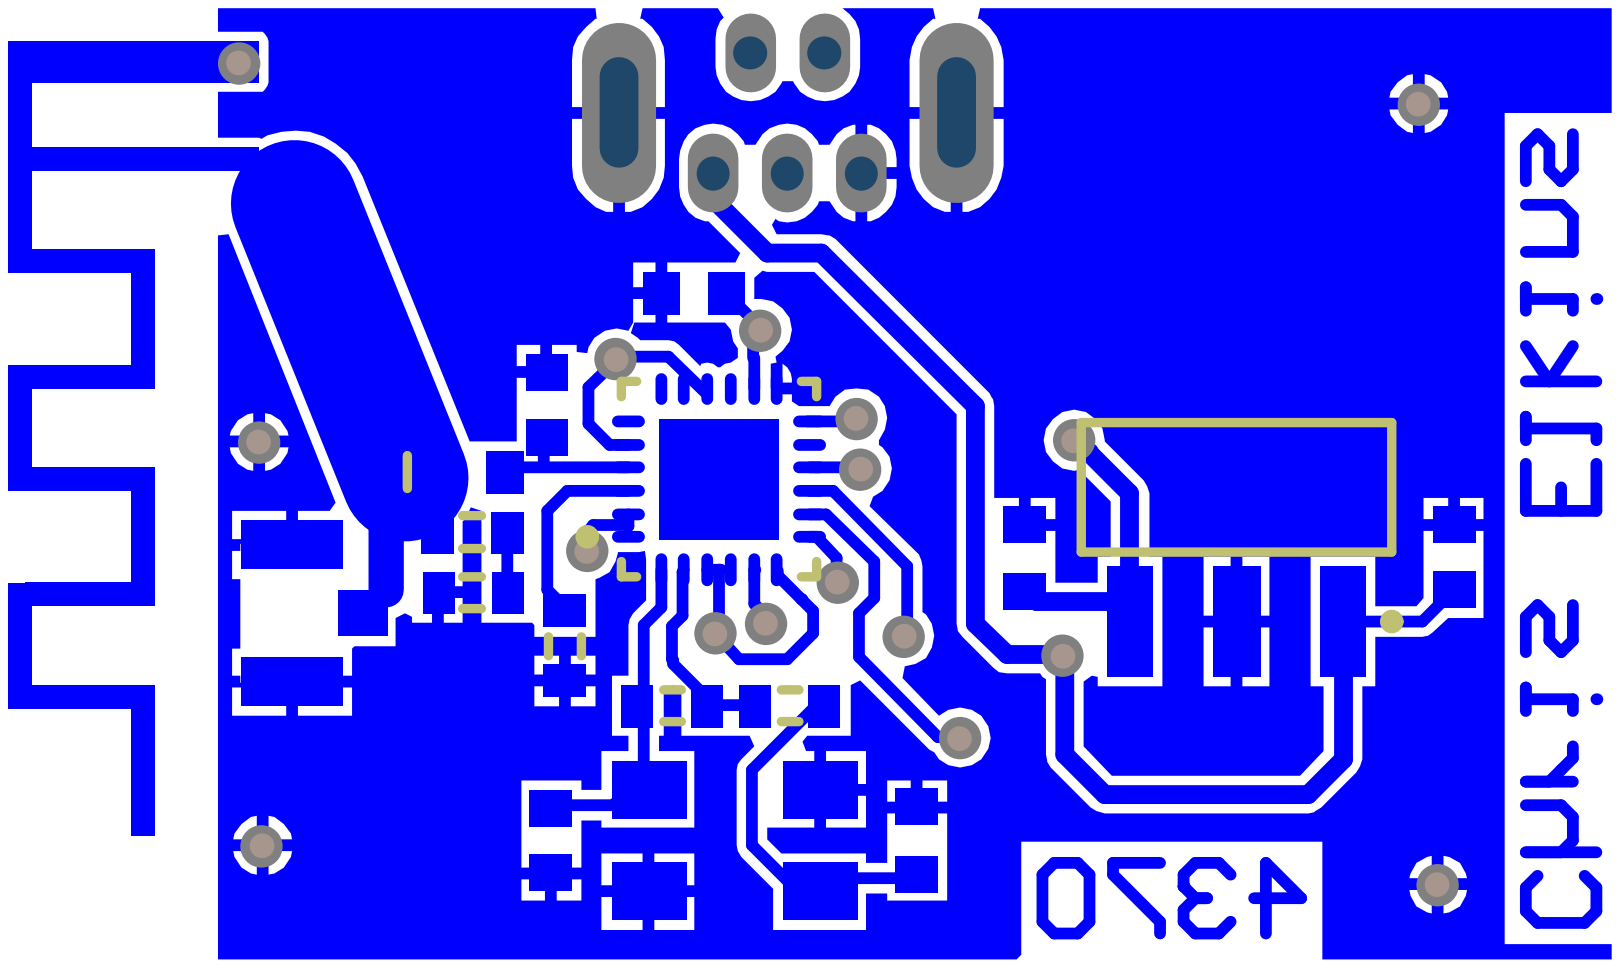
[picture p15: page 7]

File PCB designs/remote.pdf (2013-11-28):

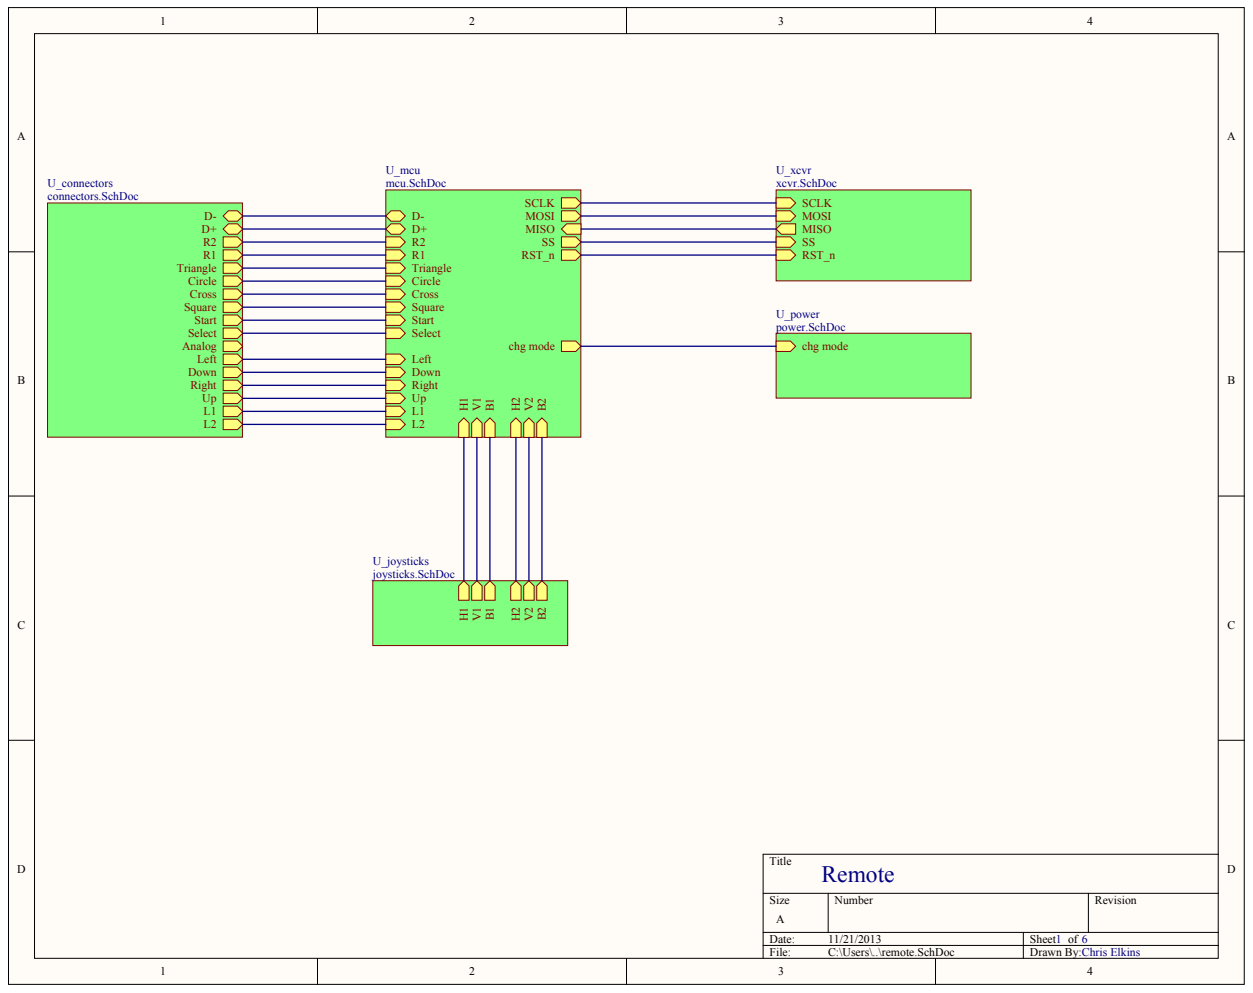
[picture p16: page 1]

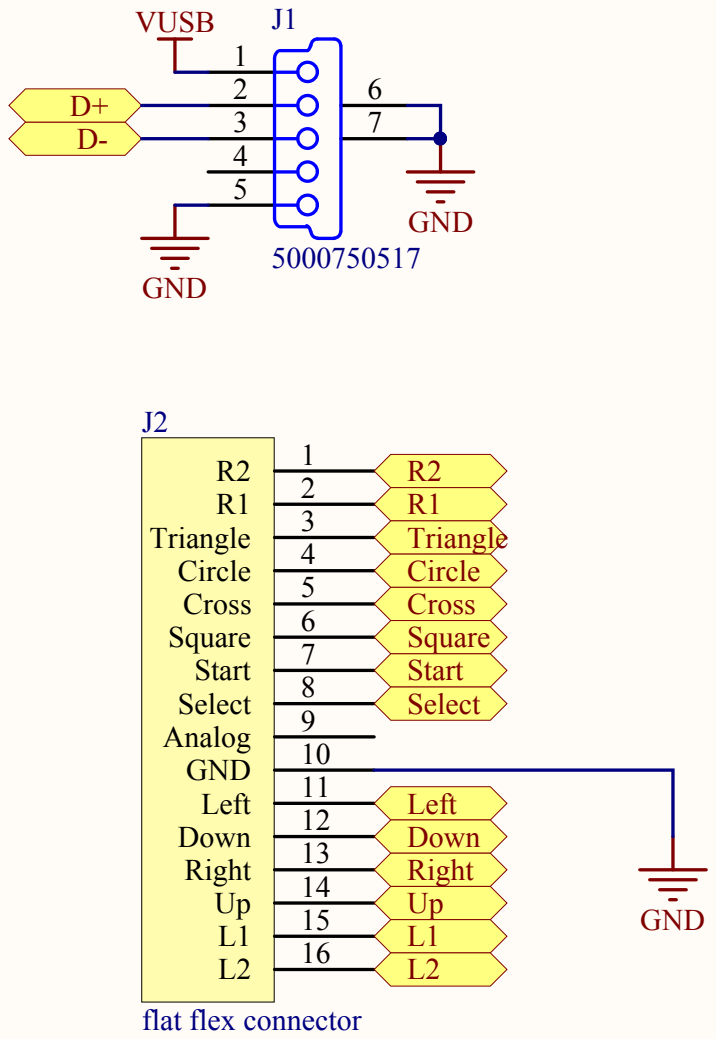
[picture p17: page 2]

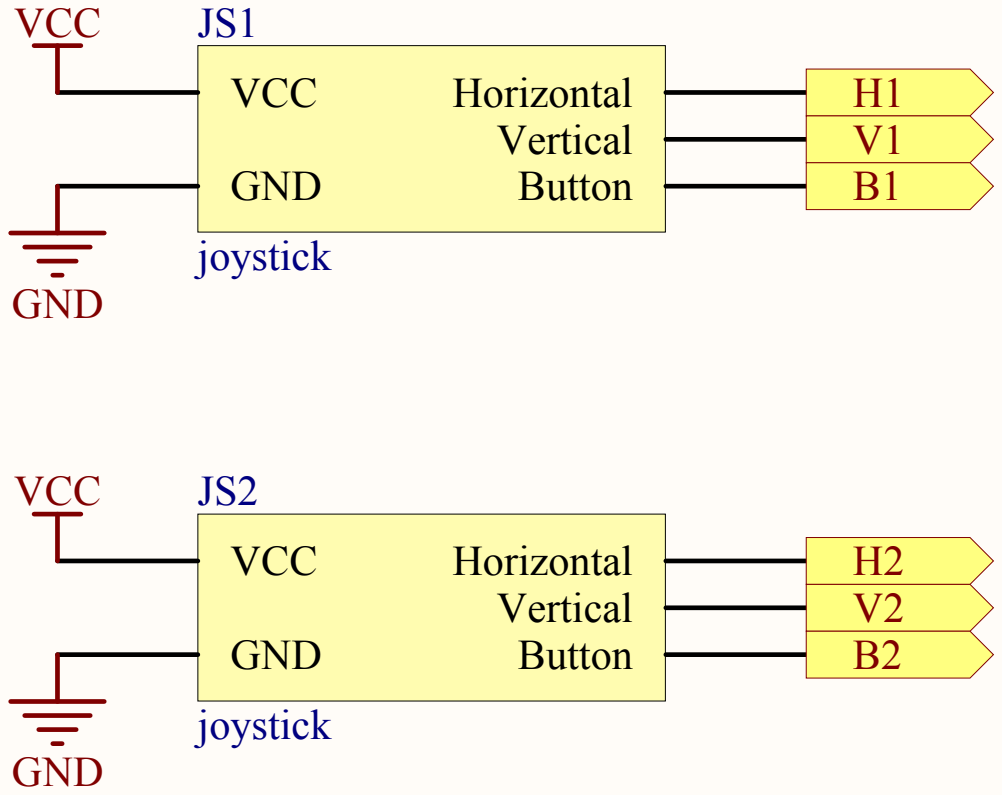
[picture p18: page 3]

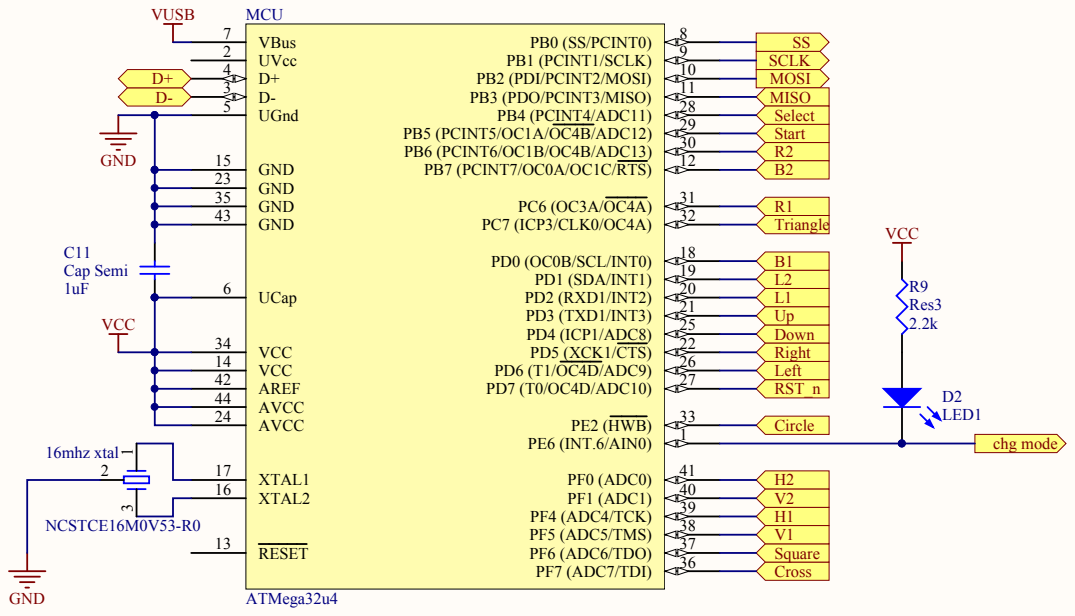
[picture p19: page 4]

GND 15
GND 23
GND 35
GND 43

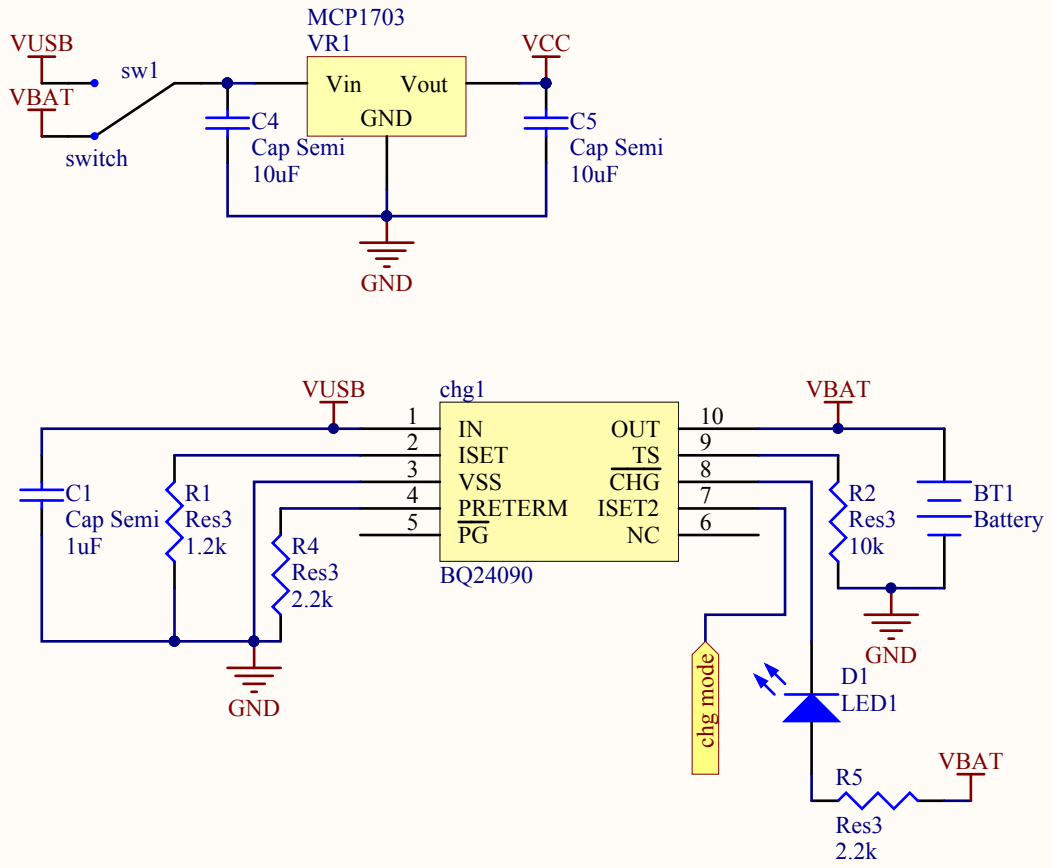
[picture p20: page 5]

ISET 2

R1 1.2k | | PRETERM 4


R6 | XTALi 24

GND 25



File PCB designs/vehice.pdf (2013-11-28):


GND 15

GND 35



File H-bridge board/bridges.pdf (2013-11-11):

SC1 Current sensing; left; bottom_left; pin1 pin2; bottom_center; bottom_right; H-Bridge; pin1; pin2; sense; sense SC4; sense SC5; Vbat; MOTOR; Right Tracks; Front Flipper; Rear Flipper; Left Tracks

Sub-circuits positioned relative to
actual positions on circuit board when
viewed from above.



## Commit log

2013-11-11 initial commit need readme
    [connectors.SchDoc, joysticks.SchDoc, mcu.SchDoc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]
2013-11-11 removing generated files
    [remote.~(54).PcbDoc]
2013-11-11 added readme moved pcb docs Signed-off-by: Chris Elkins <caelkins@ualr.edu>
    [connectors.SchDoc, joysticks.SchDoc, mcu.SchDoc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]
2013-11-28 Generated PDFs of all schematics and circuit boards to allow viewing without altium
    [reciever.PcbDoc, reciever.PrjPcb, remote.PcbDoc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]
